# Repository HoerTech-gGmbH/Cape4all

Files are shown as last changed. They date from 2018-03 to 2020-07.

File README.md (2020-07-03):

# Cape4all
Open Hardware Multichannel Sound Interface for Hearing Aid Research on Beaglebone Black

### Hardware Design Files

The published Beaglebone AD/DA Cape schematic and board layout files were developed
by the Institute of Microelectronic Systems at Leibniz Universität Hannover together
with the Videantis GmbH within DFG Cluster of Excellence EXC 1077/1 "Hearing4all".
They are published under the CC BY-NC-SA 4.0 license.

### Kernel Driver Files

These were developed by 64Studio for HörTech gGmbH. They are published under the
GPLv2 license.

See the respective directories for the full license text.

## Publication

Cape4all is described in a contribution to the Linux Audio Conference, see [LAC2018_Cape4all.pdf](LAC2018_Cape4all.pdf). 

If you want to refer to Cape4all in a publication, please cite

Herzke, T., Kayser H., Seifert, C., Maanen, P., Obbard, C., Payá-Vayá, G., Blume, H., 
Hohmann, V., “Open Hardware Multichannel Sound Interface for Hearing Aid Research on 
BeagleBone Black with openMHA: Cape4all,” Linux Audio Conference (LAC2018), May 09, 
Berlin, Germany, 2018.

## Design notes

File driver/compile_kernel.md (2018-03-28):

# Compile  Linux Kernel for Cape4All

Christopher Obbard 13/03/2018
Please mail any questions to     chris <at> 64studio.com

Download & Patch kernel sources:
```
chris@pc:~$ git clone -b linux-4.14.y git://git.kernel.org/pub/scm/linux/kernel/git/stable/linux-stable.git
chris@pc:~/linux-stable$ git apply 0001-add-cape4all-driver-v1.patch
```

Configure Kernel:
```
chris@pc:~/linux-stable$ make distclean
chris@pc:~/linux-stable$ ARCH=arm make omap2plus_defconfig
chris@pc:~/linux-stable$ ARCH=arm make menuconfig
```

Enable the CONFIG_SND_SOC_BONEBLACK_AUDIO_EXTENSION option:
```
 > Device Drivers > Sound card support > Advanced Linux Sound Architecture > ALSA for SoC audio support > <M> SoC Audio support for Boneblack Audio Extension
```

This is also required for the Boneblack board:
```
 > File systems > Native language support > <*> ASCII (United States)
```

Cross-compile Kernel, Modules and Device Tree:
```
 > chris@pc:~/linux-stable$ ARCH=arm CROSS_COMPILE=arm-linux-gnueabihf- make -j6 zImage modules dtbs
```

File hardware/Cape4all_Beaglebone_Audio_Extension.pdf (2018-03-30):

# Beaglebone Audio Extension Technical Reference Manual

## Institute of Microelectronic Systems

## Architectures and Systems Group

## Gottfried Wilhelm Leibniz Universität Hannover

Version | Author | Date | Comment
0.1 | seifert | 25.01.2011 | Document setup and introduction started.
0.2 | seifert | 31.08.2016 | Document update. | Bus collision fix in
schematic and board layout.
0.3 | seifert | 22.09.2016 | Document update. | Detailed jumper and
| | | header descriptions.
0.4 | seifert | 01.12.2017 | Document update. Bus collision fix descrip-
| | | tion in Appendix.
0.5 | seifert | 16.03.2018 | Document update. Corrected Table 3 line 10
| | | and Table 5 line 3.
Institute of Microelectronic Systems | IMS Beaglebone Audio Extension Board Spec.

## Contents

1. Introduction | 5
2. Overview | 6
3. Board Parameters | 7
4. Components | 7
5. Headers | 8
6. Jumpers | 11
List of Figures | 17
List of Tables | 18
Bibliography | 18
Appendices | 19
A. Header | 19
B. Schematics | 20
IMS Beaglebone Audio Extension Board Spec. | Institute of Microelectronic Systems

## 1. Introduction

This technical reference manual describes the functionality of the IMS Beaglebone Audio Extension Board. First an overview of the features is given. After that available headers and connectors are shown and their functionality is described. Later in this manual the jumpers and default configuration settings are listed. At the end the usage with the Beaglebone board is described together with the header pinouts, examples and schematics in the appendix.

## 2. Overview

In this section an overview of the IMS Beaglebone Audio Extension Board is given. The IMS Beaglebone Audio Extension Board is build up using three ADAU1761 low-power codecs from Analog Devices Inc.

Each of the three codecs provides the following features:

- 24-bit stereo audio ADC and DAC: >98 dB SNR
- Sampling rates from 8 kHz to 96 kHz
- Flexible analog input/output mixers
- Stereo digital microphone inputs
- PLL supporting input clocks from 8 MHz to 27 MHz
- Microphone bias reference voltage
- Analog and digital I/O: 1.8 V to 3.65 V
- I2C and SPI control interfaces
- Digital audio serial data I/O: stereo (I2S) and time-division multiplexing (TDM) modes
- 32-lead, 5 mm × 5 mm LFCSP
- -40◦C to +85◦C operating temperature range

For complete informations please refer to the ADAU1761 datasheet [1].

The IMS Beaglebone Audio Extension Board itself is equipped with three 3-pole 3.5mm jacks for stereo microphone input (MIC_IN 1-3) and two 3-pole 3.5mm jacks for stereo headphones output (HP 1-2) shown in figure 1. With the headers P8 and P9 the IMS Beaglebone Audio Extension Board is connected to any compatible Beaglebone board e.g., Beaglebone Black, Beaglebone Green.

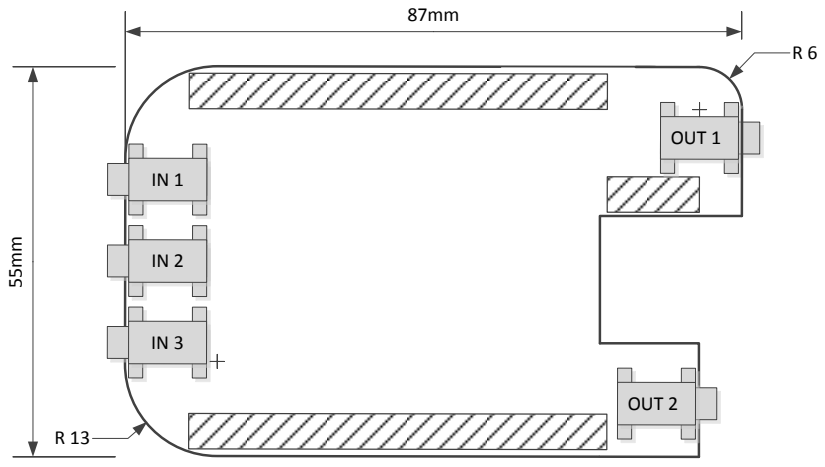
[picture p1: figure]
OUT 2; OUT 1

Figure 1: IMS Beaglebone Audio Extension Board outline

## 3. Board Parameters

- Supply Voltages

– 3.3V from Beaglebone headers P8 and P9

- Internal Voltages from 3.3V supply

– 3.3V for configuration EEPROM

– 3.0V for audio codecs

– 1.0V for hearing aid dummies or microphone bias

## 4. Components

- Power Management

– Voltage Regulation (MAX8902A, MAX8902B)

- Audio (ADAU1761)
- Memory

– Beaglebone configuration EEPROM (CAT24C256)

- Audio bus merger

– 3-input logic OR-Gate (SN74LVC1G332DBVR)

## 5. Headers

The IMS Beaglebone Audio Extension Board headers can be classified as basic headers and extension headers. In the following sections the headers and their functionality will be described.

### 5.1. Basic Headers

For basic connectivity of the IMS Beaglebone Audio Extension Board the headers and connectors listed in table 1 and shown in figure 1 are used.

Name | Type | Description
IN 1 | Audio | 3.5mm stereo microphone input 1
IN 2 | Audio | 3.5mm stereo microphone input 2
IN 3 | Audio | 3.5mm stereo microphone input 3
OUT 1 | Audio | 3.5mm stereo headphone output 1
OUT 2 | Audio | 3.5mm stereo headphone output 2
P8 | Digital | Connector for digital control and audio data transfers to/from Beaglebone.
P9 | Digital | Connector for digital control and audio data transfers to/from Beaglebone.

Table 1: IMS Beaglebone Audio Extension Board basic connectors

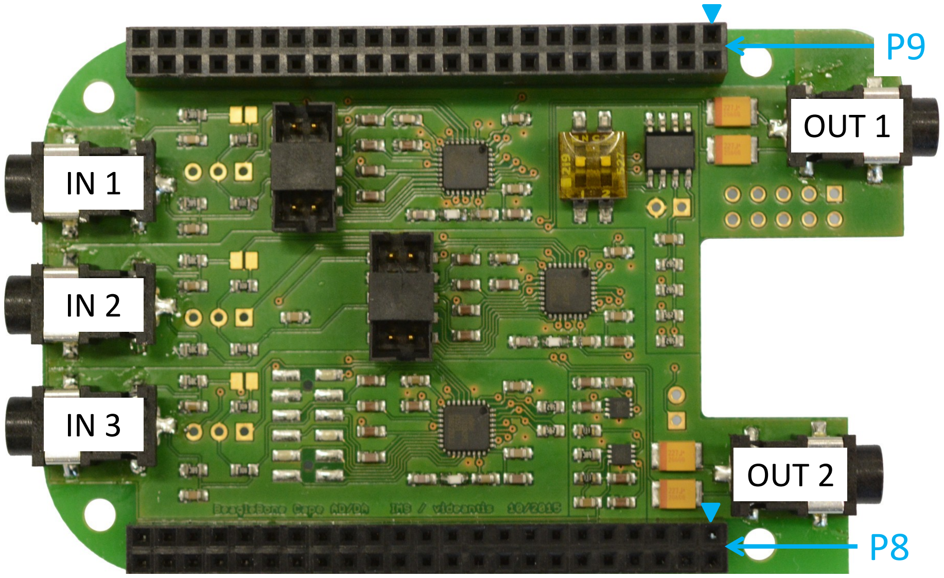
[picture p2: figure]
OUT 1; OUT 2

Figure 2: IMS Beaglebone Audio Extension Board headers

### 5.2. Extension Headers

When more specific connectivity is needed there are some extension headers that provide line level inputs, digital microphone inputs, and line-level outputs. A list of the connectors and headers is given in table 2 and shown in figure 2.

Name | Type | Description
X1 | Mixed | 10-pin audio extension header (2mm pitch)
X2 | Mixed | 10-pin audio extension header (2mm pitch)
X3 | Mixed | 12-pin audio extension header (2mm pitch)

Table 2: IMS Beaglebone Audio Extension Board extension headers

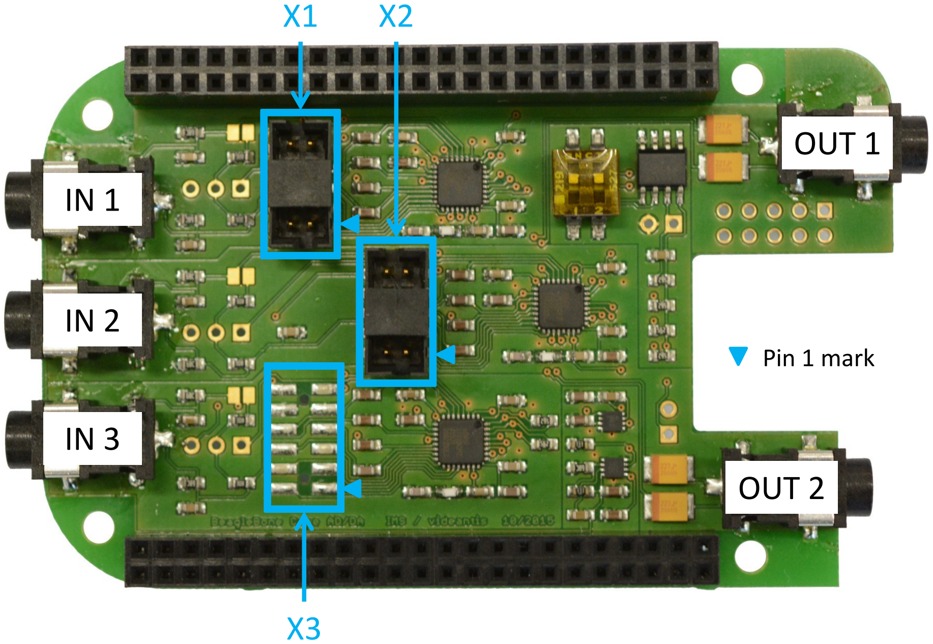
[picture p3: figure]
OUT 1; OUT 2; Pin 1 mark

Figure 3: IMS Beaglebone Audio Extension Board headers

The pinouts of the X1 and X2 headers are symmetrical. Therefore, the pinout of the X1 header is shown in figure 4 and all headers are shown in appendix section A. All the signals with a suffix of 6 belong to the first codec IC1, the suffix 7 belongs to the second codec IC2 and so on. As codec 3 has no dedicated headphone output jack, the pins were added to the X3 header, which can be seen in section A.

Figure 4: IMS Beaglebone Audio Extension Board X1 header pinout

Pin | Name | Description
1 | LOUTN | Left differential line output, negative. Biased
| | at AVDD/2.
2 | LOUTP | Left differential line output, positive. Biased
| | at AVDD/2.
3 | ROUTN | Right Line Output, Negative. | Biased at
| | AVDD/2.
4 | ROUTP | Right Line Output, Positive. | Biased at
| | AVDD/2.
5 | RAUX | Right Channel Single-Ended Auxiliary In-
| | put. Biased at AVDD/2.
6 | LAUX | Left Channel Single-Ended Auxiliary Input.
| | Biased at AVDD/2.
7 & 8 | - | GND connection.
9 | JACKDET | Detect Insertion/Removal of Headphone
| | Plug (JACKDET).
Digital Microphone Stereo Input (MICIN).
10 | +1V | +1V regulated power supply output. En-
| | abled via X5 shown in figure 8

Table 3: IMS Beaglebone Audio Extension Board extension headers

For more information on the pins 1 to 10 of the headers X1-3 please refer to the ADAU1761 datasheet [1].

The digital general-purpose IOs are directly connected to the Beaglebone connectors P8 and P9. The functionality depends on the connected beaglebone board.

## 6. Jumpers

This section describes the configuration jumpers and their default configuration. Also the detailed functionality is given in case of non-default settings.

### 6.1. Microphone input configuration

On the IMS Beaglebone Audio Extension Board there are two jumpers for each microphone input configuration. Another jumper is used for an additional bias voltage supply for all microphone inputs and described in section 6.3. In table 4 the jumpers for each microphone input are listed and after that a schematic and functionality description is given.

Jumper | Microphone-Input | Description
JP11 | IN 1 | Mic. bias enable right channel.
JP12 | IN 1 | Mic. bias enable/selection left channel.
JP21 | IN 2 | Mic. bias enable right channel.
JP22 | IN 2 | Mic. bias enable/selection left channel.
JP31 | IN 3 | Mic. bias enable right channel.
JP32 | IN 3 | Mic. bias enable/selection left channel.

Table 4: IMS Beaglebone Audio Extension Board microphone input jumpers.

For better understanding the schematic of one of the microphone inputs is given in figure 5.

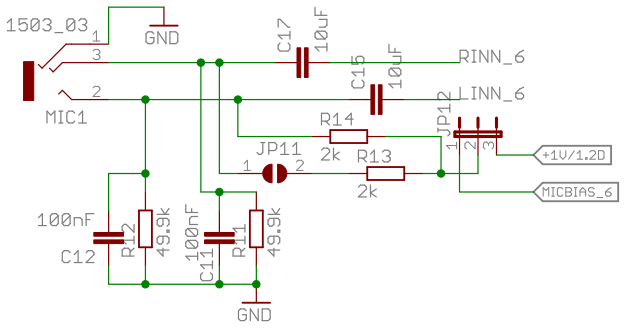
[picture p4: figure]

Figure 5: IMS Beaglebone Audio Extension Board microphone input 1 schematic.

As shown in figure 5 there are mainly two jumpers on each channel for bias voltage configuration. The jumper JPx2 (here x is 1-3) selects the bias voltage source between the bias output of the corresponding codec (in figure 5 codec 6) and a configurable voltage regulator that is set to 1 Volt output in default setting. When selecting one of the bias voltage sources, the supply will be connected to the left input channel (the tip of the 3.5mm input jack) accordingly. If there is also a bias supply needed on the right channel (the ring of the 3.5mm input jack) the jumper JPx1 needs to be shorted. The possible settings of the jumpers are listed in table 5.

| JPx2 | JPx1 | Description
1 | open | open | No bias supply on microphone input.
2 | 1-2 | open | Bias supply of 3.5mm tip with configurable codec
| | | bias output.
3 | 2-3 | open | Bias supply of 3.5mm tip with configurable voltage
| | | regulator output. 1 Volt by default.
4 | 1-2 | shorted | Bias supply of 3.5mm tip and ring with config-
| | | urable codec bias output.
5 | 2-3 | shorted | Bias supply of 3.5mm tip and ring with config-
| | | urable voltage regulator output. 1 Volt by default.

Table 5: IMS Beaglebone Audio Extension Board microphone jumper settings.

Figure 6 shows a detailed view of the microphone input jumpers.

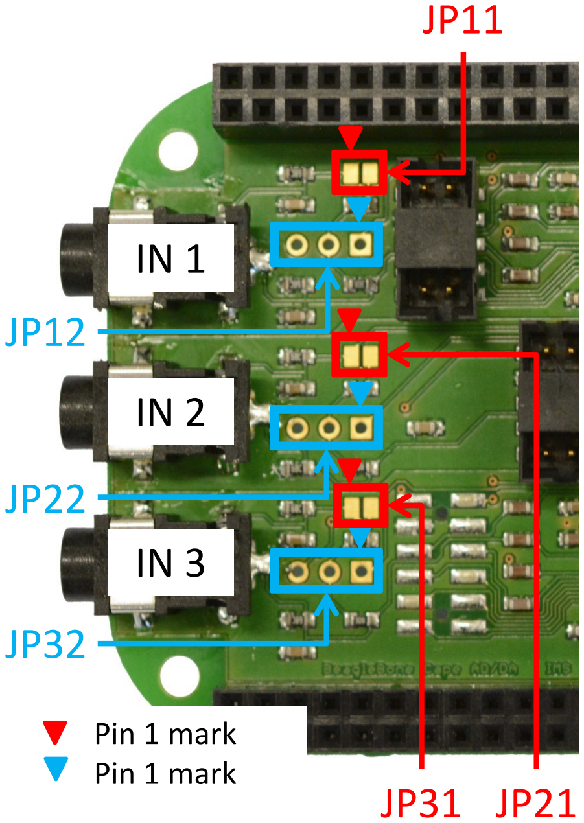
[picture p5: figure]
Pin 1 mark Pin 1 mark

Figure 6: IMS Beaglebone Audio Extension Board microphone input jumpers.

For the voltage regulator settings for bias supply please refer to section 6.3.

### 6.2. Headphone Output

After the microphone input jumpers have been described, this section gives a detailed description of the headphone outputs. The schematic of one headphone output is given in figure 7, while the other headphone output is built up accordingly.

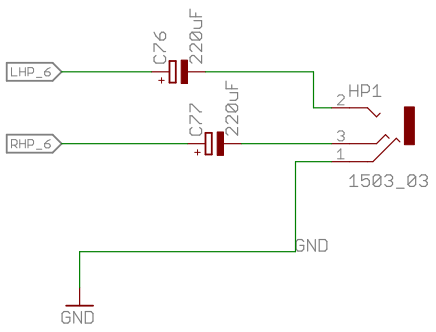
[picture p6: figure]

Figure 7: IMS Beaglebone Audio Extension Board headphone output 1 schematic.

There are DC-blocking capacitors built-in for headphones without built-in capacitors.

### 6.3. Power and EEPROM configuration

This section describes the jumpers for power and EEPROM configuration on the IMS Beaglebone Audio Extension Board. There are two jumpers and one dual switch used for the configuration, which is listed in table 6.

Jumper | Type | Description
X5 | Power | 1V voltage regulator enable if shorted.
X4 | EEPROM | Write protect disabled if shorted.
S4 | EEPROM | Address selection 00, if both switches on.

Table 6: IMS Beaglebone Audio Extension Board power and EEPROM jumpers.

The location of the jumpers is shown in 8.

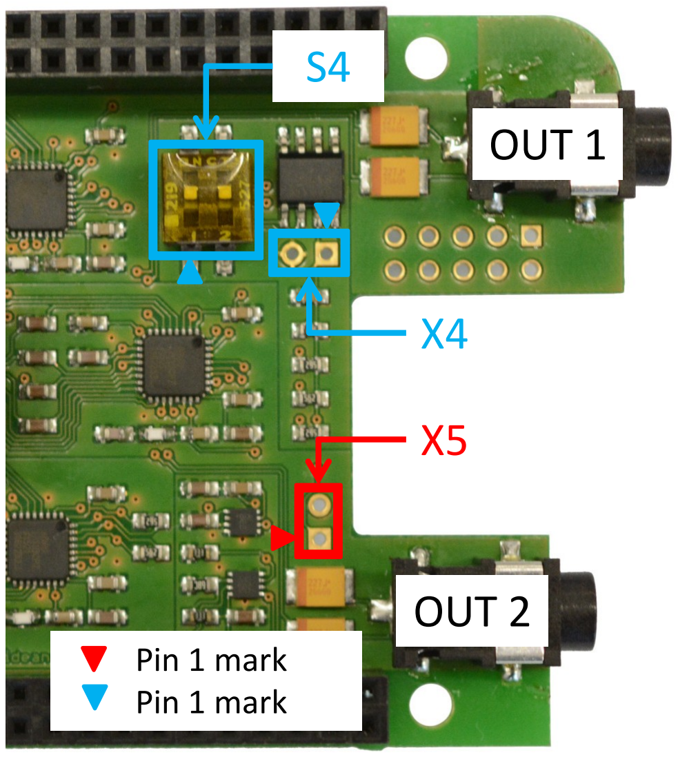
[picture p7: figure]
OUT 1; OUT 2; Pin 1 mark Pin 1 mark

Figure 8: IMS Beaglebone Audio Extension Board power and clock jumpers.

### 6.3.1. Power configuration

The configuration of the microphone bias power supply is done using the X5 jumper. All configurations are listed in table 7.

| X5 | Description
1 | 1-2 | Voltage regulator enabled.
| | Output voltage +1V configured with R51 and R52.
2 | open | Voltage regulator disabled. (Default)

Table 7: IMS Beaglebone Audio Extension Board power jumper settings.

A detailed schematic of the regulator and jumper is given in figure 9.

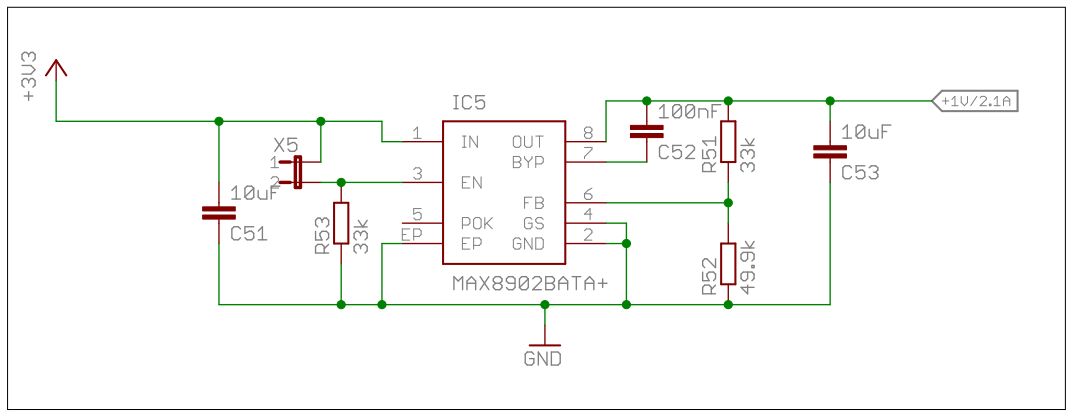
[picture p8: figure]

Figure 9: IMS Beaglebone Audio Extension Board voltage regulator circuit.

### 6.3.2. EEPROM configuration

The configuration of the EEPROM is done with one jumper and a switch. All jumper configurations are listed in table 8.

| X4 | Description
1 | 1-2 | EEPROM write protection disabled (only for ini-
| | tial programming).
2 | open | EEPROM write protection enabled. (Default)

Table 8: IMS Beaglebone Audio Extension Board EEPROM jumper settings.

A detailed schematic of the EEPROM and jumper is given in figure 9.

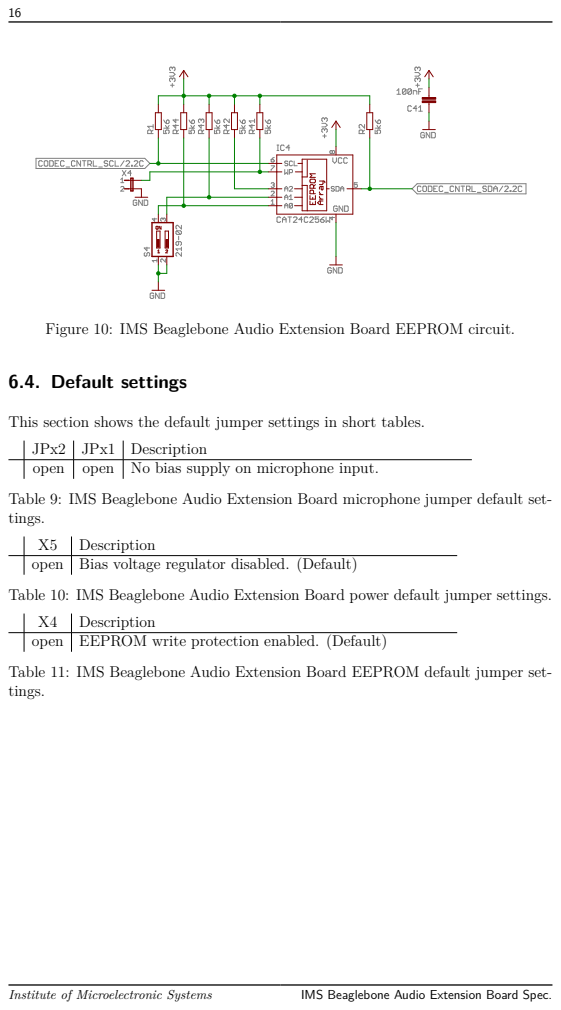
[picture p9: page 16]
6.4. Default settings; JPx2; JPx1; Description; open; No bias supply on microphone input.; Bias voltage regulator disabled. (Default); EEPROM write protection enabled. (Default)

Figure 10: IMS Beaglebone Audio Extension Board EEPROM circuit.

This section shows the default jumper settings in short tables.

Table 9: IMS Beaglebone Audio Extension Board microphone jumper default set-
tings.

Table 10: IMS Beaglebone Audio Extension Board power default jumper settings.

Table 11: IMS Beaglebone Audio Extension Board EEPROM default jumper set-

## List of Figures

5. IMS Beaglebone Audio Extension Board microphone input 1 schematic. 11
6. IMS Beaglebone Audio Extension Board microphone input jumpers. 12
7. IMS Beaglebone Audio Extension Board headphone output 1 schematic. 13
8. IMS Beaglebone Audio Extension Board power and clock jumpers. . 14
9. IMS Beaglebone Audio Extension Board voltage regulator circuit. . 15
14. IMS Beaglebone Audio Extension Board microphone input schematic 20
16. IMS Beaglebone Audio Extension Board headphone output schematic 21
17. IMS Beaglebone Audio Extension Board power supplies schematic . 22
18. IMS Beaglebone Audio Extension Board ADC audio data bus merg-
19. IMS Beaglebone Audio Extension Board schematic P6 & P8 headers 23
20. IMS Beaglebone Audio Extension Board schematic P9 header . . . 23

## List of Tables

4. IMS Beaglebone Audio Extension Board microphone input jumpers. 11
5. IMS Beaglebone Audio Extension Board microphone jumper settings. 12
6. IMS Beaglebone Audio Extension Board power and EEPROM jumpers. 14
7. IMS Beaglebone Audio Extension Board power jumper settings. . . 15
8. IMS Beaglebone Audio Extension Board EEPROM jumper settings. 15
9. IMS Beaglebone Audio Extension Board microphone jumper default
10. IMS Beaglebone Audio Extension Board power default jumper set-
11. IMS Beaglebone Audio Extension Board EEPROM default jumper

## References

[1] Analog Devices Inc. Adau1761 - sigmadsp stereo, low power, 96 khz,24-bit audio codec with integrated pll. http://www.analog.com/static/importedfiles/data_sheets/ADAU1761.pdf, 2009.

## A. Header

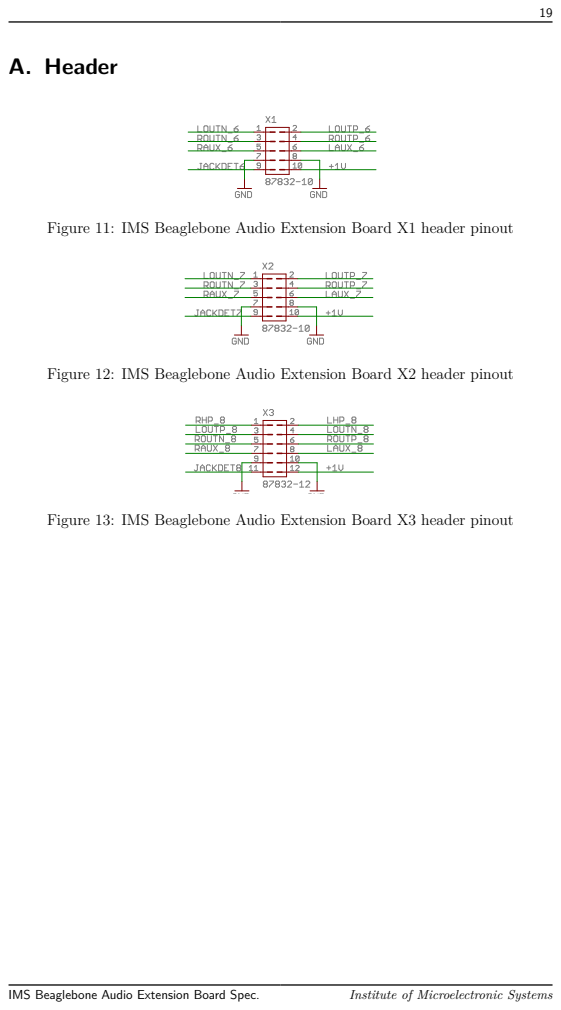
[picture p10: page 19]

Figure 11: IMS Beaglebone Audio Extension Board X1 header pinout

Figure 12: IMS Beaglebone Audio Extension Board X2 header pinout

Figure 13: IMS Beaglebone Audio Extension Board X3 header pinout

## B. Schematics

This section and its subsections show the detailed schematic of the IMS Beaglebone Audio Extension Board.

### B.1. Audio component schematics

The microphone, codec and headphone output schematics are shown for one codec only, as all codecs are connected in the same manner using the indexes 6 to 8. Due to a non tri-state output of the codecs digital audio output pin, the digital audio bus signals of the three codecs CODEC_AUDIO_ADC_SDATA_A, CODEC_AUDIO_ADC_SDATA_B and CODEC_AUDIO_ADC_SDATA_C are merged by the OR gate (IC7) shown in Section B.2.2. This does only provide electrical data corruption. It does not remove data collision due to wrong output timing (like overlap) of the audio codecs. The correct timing slots have to be configured in the codec configuration registers for 4 or 8 channel TDM.

B.1.1. Microphone input

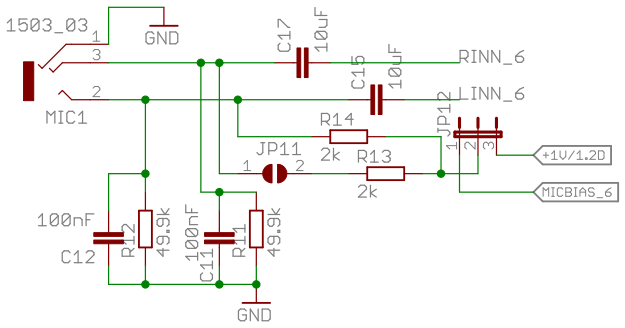
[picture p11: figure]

Figure 14: IMS Beaglebone Audio Extension Board microphone input schematic

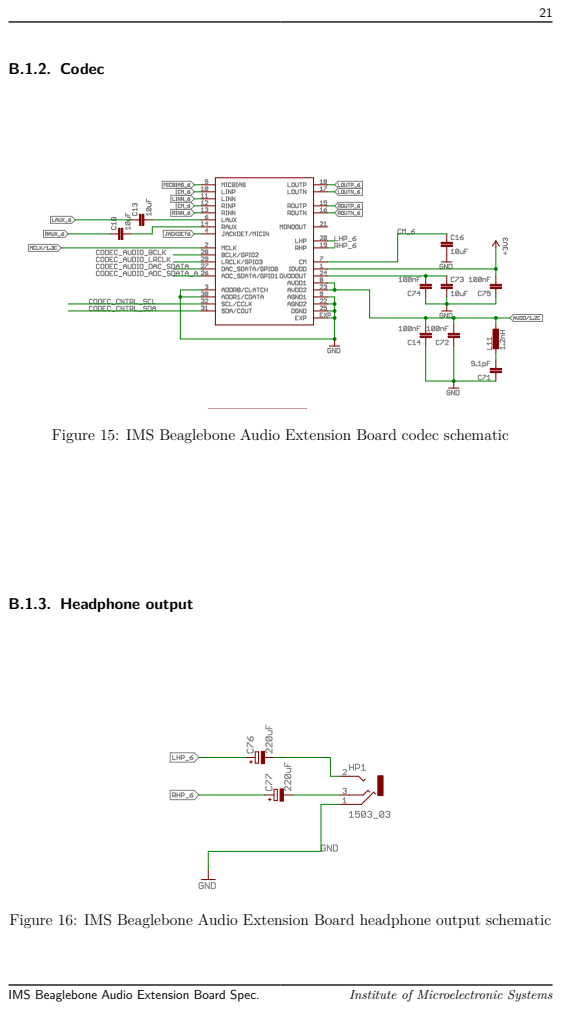
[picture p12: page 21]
B.1.2. Codec; B.1.3. Headphone output

Figure 15: IMS Beaglebone Audio Extension Board codec schematic

Figure 16: IMS Beaglebone Audio Extension Board headphone output schematic

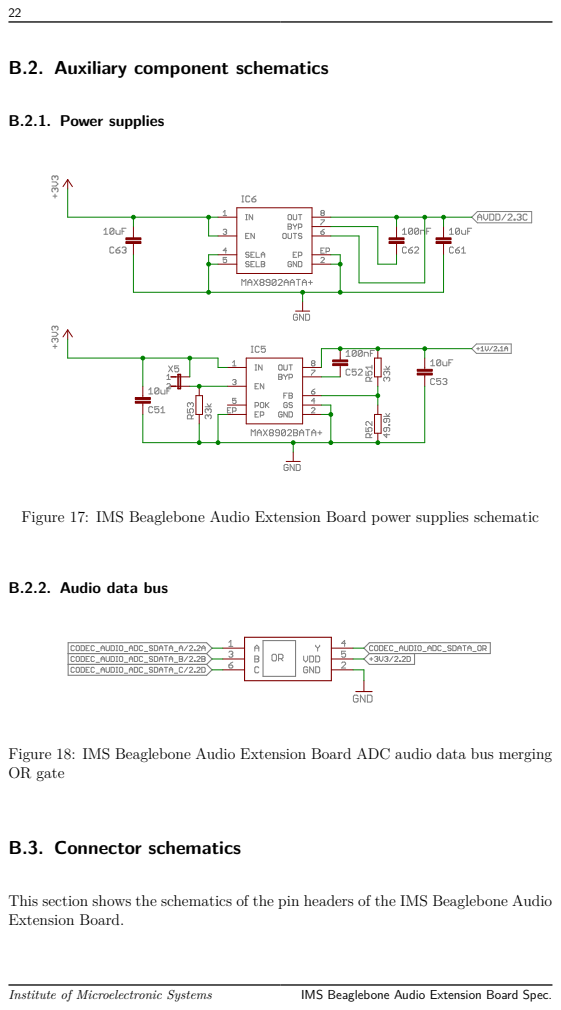
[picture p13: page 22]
B.2.1. Power supplies; B.3. Connector schematics

B.2. Auxiliary component schematics

Figure 17: IMS Beaglebone Audio Extension Board power supplies schematic

B.2.2. Audio data bus

Figure 18: IMS Beaglebone Audio Extension Board ADC audio data bus merging
OR gate

This section shows the schematics of the pin headers of the IMS Beaglebone Audio
Extension Board.

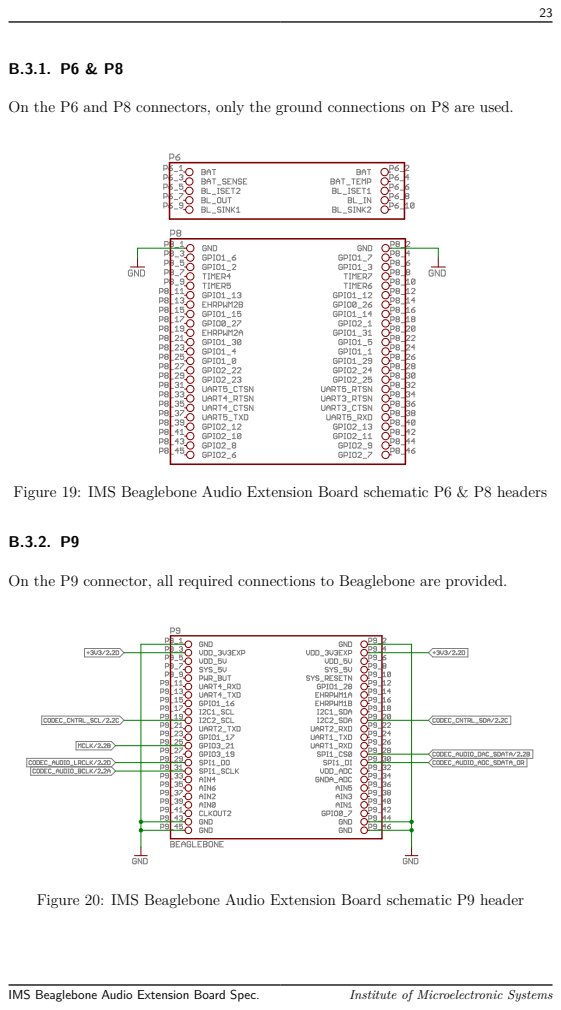
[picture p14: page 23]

On the P6 and P8 connectors, only the ground connections on P8 are used.

Figure 19: IMS Beaglebone Audio Extension Board schematic P6 & P8 headers

On the P9 connector, all required connections to Beaglebone are provided.

Figure 20: IMS Beaglebone Audio Extension Board schematic P9 header

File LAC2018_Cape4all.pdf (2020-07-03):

## Open Hardware Multichannel Sound Interface for Hearing Aid Research on BeagleBone Black with openMHA: Cape4all

Tobias Herzke¹,4 and Hendrik Kayser¹,2,4 and Christopher Seifert³,4 and Paul Maanen¹,4 and Christopher Obbard⁵ and Guillermo Payá-Vayá³,4 and Holger Blume³,4 and Volker Hohmann¹,2,4 1HörTech gGmbH, Marie-Curie-Str. 2, D-26129 Oldenburg, Germany 2Medical Physics, Carl von Ossietzky Universität Oldenburg, D-26111 Oldenburg, Germany

3
Institute of Microelectronic Systems, Leibniz Universität, D-30176 Hannover, Germany 4Cluster of Excellence “Hearing4all” 564 Studio Ltd, Isle of Wight, UK info@openmha.org

Abstract

The paper describes a new multichannel sound interface for the BeagleBone Black, Cape4all. The sound interface has 6 input channels with optional microphone pre-amplifiers and between 4 and 6 output channels. The multichannel sound extension cape for the BeagleBone Black is designed and produced. An ALSA driver is written for it. It is used with the openMHA hearing aid research software to perform hearing aid signal processing on the Beagle-Bone Black with a customized Debian distribution tailored to real-time audio signal processing.

Keywords

Hearing aids, audio signal processing, sound hardware

### 1 Introduction

Hearing aids are the most common form of mitigation for mild and moderate hearing losses. Hearing aids help the wearer to follow conversations and acoustic events in different situations. In the complex acoustic environments that we encounter in our daily life, information about the acoustic scene is inferred at higher stages of the human auditory system and exploited in the brain for, e.g., speech understanding. A hearing loss causes — in addition to reduced sensitivity to soft sounds — a partial loss of this information. Effective signal processing algorithms are required for compensation. For this reason, improving signal processing in hearing aids is an active research topic.
Part of the work in hearing aid research is to develop novel signal processing algorithms that can be used in hearing aids to improve the hearing experience for hard-of-hearing people. Usually, simulations are run and evaluated in terms of objective measures after such an algorithm has been developed mathematically. Results from simulations do not necessarily reflect the benefit of the algorithm a) when integrated in a complete signal processing chain of a hearing aid and b) in a real-world scenario. To assess the usefulness of new hearing aid algorithms for hearing-impaired people, new potential hearing aid signal processing algorithms also have to be tested with hearing impaired test subjects in realistic situations. Running an algorithm under test on an end-user hearing device is practically infeasible as it requires access to a proprietary system of a hearing aid manufacturer, and a large effort for the down-to-hardware implementation is required on such devices. Instead, a software platform can be used to simulate the hearing aid processing chain. The open Master Hearing Aid (openMHA, [HörTech gGmbH and Universität Oldenburg, 2017], [Herzke et al., 2017]) is such a platform. openMHA can be utilized to conduct field tests of hearing aid processing methods running on portable hardware.

The following sections first introduce the software and hardware platforms utilizable to evaluate hearing aid algorithms with hearing-impaired test subjects. We work out the need for a custom multichannel sound interface for a small, portable computer. The subsequent sections report on the hardware design process that resulted in the Cape4all¹ BeagleBone sound interface, the sound driver development, and finally the possible usage of the sound interface for hearing aid research.

1developed in the cluster of excellence “Hearing4all”

### 2 Software and Hardware Platform

for Hearing Aid Research

HörTech and the University of Oldenburg have developed the openMHA [HörTech gGmbH and Universität Oldenburg, 2017], [Herzke et al., 2017] software platform for the development and evaluation of hearing aid algorithms, where individual hearing aid algorithms can be implemented as plugins and loaded at run-time. The platform provides a set of standard algorithms to form a complete hearing aid. It can process audio signal in real-time with a low delay (<10 ms) between sound input and sound output. (The actual delay depends on the sound hardware used for input and output, configuration options like sampling rate and audio buffer size, and also on delay introduced by some signal processing algorithms.)
In its current version 4.5.5, the openMHA software platform can execute on computers with Linux and Mac OS operating system, e.g., in a laboratory environment. Toolboxes for generating virtual sound environments in a laboratory exist (e.g. TASCAR [Grimm et al., 2015]) but the sound environment in a lab — and even more the subject behavior in a lab environment — will always differ from real environments encountered by hearing aid users in real life. To test real-life situations, we have to go outside and into real situations with hearing-impaired users wearing a mobile computer that executes the openMHA and provides the first chance to test new algorithms in real-world situations. In the past, we have used laptops for this purpose but with the advent of small, ARM-based single board computers like the Raspberry Pi, Beagle-Bone, and several others these become an option for executing openMHA that imposes less weight to carry around for the test subjects. The processing power of these devices is significantly lower than that of PCs and laptops, which will always limit the extent and setup of algorithms that can be executed on such a mobile platform (compared to a PC).
openMHA is meant as a common platform to be used by different hearing aid research labs to combine their work. By providing a solid base platform, we want to encourage researchers to implement and publish their algorithms as openMHA plugins so that work can be shared and results can be reproduced by independent labs.
For this purpose, openMHA includes a toolbox library that already contains functions and classes useful to more than one algorithm to speed up implementation of new algorithms. As a key to usability of the software in different usage scenarios openMHA also includes several manuals for different entry levels ranging from plugin developments over application engineering based on available plugins and functionality to the application of the software in the context of audiological research and hearing aid fitting controlled through a graphical user interface (GUI). Step-by-step tutorials on the implementation of openMHA plugins as well as examples of configurations are provided to enable an autonomous familiarization for new users. Some hearing aid algorithms — such as directional microphones — need to process the sound from more than one microphone per ear which is why a multichannel sound card is generally needed to capture the sound from all hearing aid microphones. Professional sound cards can be used for this purpose in stationary laboratory setups. Bus-powered USB sound cards can be used with laptops in mobile evaluation setups, but the choice of bus-powered interfaces with more than 2 input channels is limited. We have observed that the total delay between input and output sounds that can be achieved with USB sound cards is always larger than what can be achieved with similar sound cards with PCI or Expresscard interface. This difference in delay is in the order of 2 ms, which will already affect some hearing aid algorithms. We have also observed that the delay may vary from one start of the sound card to the next with USB sound cards, in the range of 1 ms, which is detrimental to some processing algorithms such as acoustic feedback reduction. (Feedback reduction algorithms are an essential part of a hearing aid processing chain and need the system to be as invariant as possible to work effectively.) The Inter-IC Sound (IIS or I²S) bus — transporting sound data from the SoC²
to the audio codecs
with the AD/DA converters (and back) — is accessible on expansion headers on many of the single-board ARM computers, making it possible to create custom sound interface hardware. Third parties already provide multichannel sound interfaces for popular boards like the BeagleBone Black and the Raspberry Pi. Of these two devices, the BeagleBone Black has the advantage of hardware support for multichannel

2Abbreviation for System on a Chip, the combination of a microprocessor and several peripherals (e.g. graphics unit, sound interface) on a single chip.

audio input/output. See Section 3.1 for details. One multichannel sound interface option for the BeagleBone Black is the BELA cape [Moro et al., 2016]. It provides stereo in/out and additional 8 analogue data acquisition channels. These additional 8 analogue data acquisition channels can also be used to capture audio but do not provide anti-aliasing filters, and achievable sampling rates depend on the number of channels in simultaneous use. The BELA cape makes use of real-time hardware present on the BeagleBone Black. Audio processing algorithms can be compiled to execute on this real-time hardware, process the input channel data, and produce output channel data. Existing Linux audio processing applications using ALSA³ or JACK⁴
[Davis, 2003] and common features of the operating system cannot execute on this real-time hardware.
Another multichannel audio interface developed for BeagleBone platforms is the CTAG face 2|4 [Langer and Manzke, 2015], [Langer, 2015]. Its hardware design is available opensource from GitHub and drivers have been included in official BeagleBoard SD card images. Providing capabilities for multichannel signal processing this device is in principle suitable for hearing aid processing on the BeagleBone Black. A drawback that remains here is the necessity to add external power supply for the microphones connected to the device.
The Octo Audio Injector sound card http: //www.audioinjector.net/rpi-octo-hat offers 6 input channels and 8 output channels for the Raspberry Pi. Although the Raspberry Pi offers no hardware support for more than two sound channels, this sound card manages to offer enough input channels to connect 2 hearing aids with 3 microphones each. A disadvantage of this sound card for hearing aid research is that additional external microphone preamplifiers are needed to raise the microphone signals to line level, which adds to the hardware that test subjects would have to carry around. An example setup for teaching hearing aid signal processing [Schädler, 2017], [Schädler et al., 2018] uses the stereo version of this sound card

3Acronym for Advanced Linux Sound Architecture, name for a system of Linux kernel sound card drivers and user space API to exchange sound data with these drivers.
4 Self-referencing acronym for JACK Audio Connection Kit, a user-space server application and library to connect inputs and outputs of audio applications and sound cards.

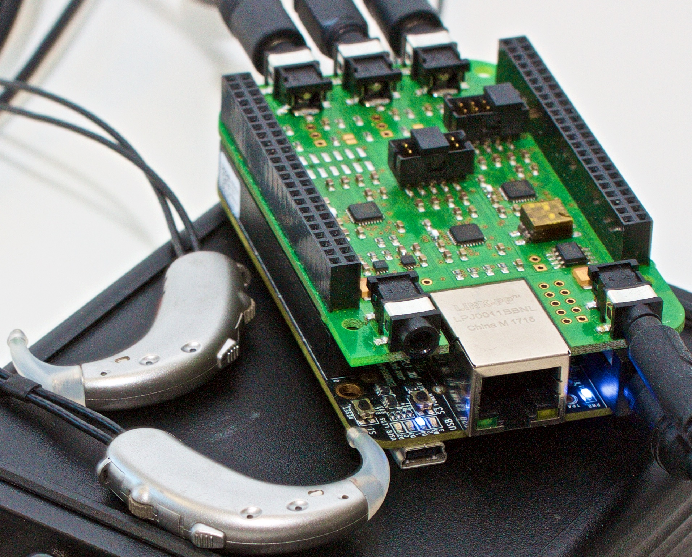
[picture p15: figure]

Figure 1: Cape4all with two hearing aids (each containing three microphones) connected.

together with external microphone preamplifiers.

### 3 Development of the Cape4all

Multichannel Sound Interface for Hearing Aid Research

We have a need for a compact multichannel sound interface for a single-board ARM computer with integrated microphone pre-amplifiers for hearing aid research. Since such a multichannel sound interface was not available, we decided to develop such a sound interface ourselves.

### 3.1 Choice of ARM Board Basis for a

Multichannel Sound Card
In the ongoing developments of the Cluster of Excellence ”Hearing4all”⁵
several audio interfaces were developed proving the inter IC sound (IIS or I²S) in combination with the Analog Devices ADAU1761 [Analog Devices Inc., 2009] stereo audio codec useful [Seifert et al., 2015]. To gain multichannel capabilities, a time division multiplex (TDM) scheme specified for I²S is used. The chosen ADAU1761 codecs support a TDM output scheme. To allow the usage in combination with an ARM-based platform and therefore with openMHA, the BeagleBone Black with native I²S TDM support by the integrated McASP⁶
interfaces was chosen.

### 3.2 Hardware Design

The Cape4all hardware was designed by the Leibniz University Hannover based on [Seifert

5
http://hearing4all.eu/
6Abbreviation for Multichannel Audio Serial Port.

et al., 2015].
In addittion to the I²S TDM output capabilities the Analog Devices ADAU1761 audio codecs have integrated microphone amplifiers. Up to 3 microphones for each ear on a bilateral fitting are assumed in the context of hearing device development. Therefore, 3 stereo audio codecs are integrated on the Cape4all PCB⁷ allowing up to 6 input and output channels simultaneously. Due to the TDM scheme, only five signal connections are required to transport and synchronize all 3 codecs with 6 input and output channels and the McASP interface of the BeagleBone Black.
The board provides standard stereo jacks for connecting off-the-shelf sound hardware as well as pin headers for custom designs. 3 stereo jacks are mounted on the board for the 6 input channels, and 2 additional stereo jacks for the first 4 output channels. The remaining output channels are only accessible through the pin headers. An on-board voltage regulator provides microphone bias voltage which can be switched on and off as needed and routed to different connectors. The bias voltage can be altered by exchanging on-board resistors. For more details, see the reference manual provided with the hardware design files and the driver as download from https://github.com/HoerTech-gGmbH/Cape4all. (https://github.com/HoerTech-gGmbH/Cape4all) Figure 1 shows the hardware in use.

### 3.3 Hardware Tests and Design

Revisions
In the testing process of previously built audio interface boards using the ADAU1761 stereo audio codecs, it was revealed that the internal components of the codecs create bus collision. The I²S TDM bus digital output pins of the codecs do not provide high-resistance state, driving the signal high or low preventing another codec to put data on the same signal. The documentation of the codecs did not give any details helping to avoid the bus collision. In order to avoid this, an OR-gate was added to the board design to merge the signals of the codecs to one signal. This solves the problem on voltage level but does not prevent timing collision due to wrong configuration of the codec outputs. The correct codec configuration is ensured by the ALSA driver (see Section 4). In normal TDM configuration, filling 6 of the available 8 timeslots, all 3 audio codecs are working cor-

7Abbreviation for Printed Circuit Board.

rectly. For further details on I²S TDM signaling see [Seifert et al., 2013].

### 3.4 Release as Open Hardware

The hardware design files are released un-
der | the | Creative | Commons | Attribution-
NonCommercial-ShareAlike | 4.0 | Inter-
national | License | on | GitHub | https:
//github.com/HoerTech-gGmbH/Cape4all.

### 4 Driver development

The ALSA sound driver for the Cape4all sound interface was developed by 64 Studio.
As the Linux kernel already has support for both the McASP Audio Serial Port [Pandey et al., 2009] used on the BeagleBone Black and the ADAU1761 codec [Clausen, 2014] used on the Cape4all, the development by 64 Studio was to create a glue-driver explaining to the SoC the order the codecs are arranged on the Cape4all. The driver registers the cape as effectively one PCM device with three mixer sub-devices (corresponding to the three physical ADAU1761 codecs), each with their own set of controls in the ALSA mixer. Also, the driver sets up the codec’s clock-path, TDM slots and various other default settings.
As the driver exposes the Cape4all as a regular ALSA device with three mixer sub-devices, each with their own ALSA controls, application software may communicate with these devices without any modifications.

### 4.1 Limitations

The McASP used on the BeagleBone Black is clocked from a 24.576 MHz crystal. This limits the available sample rates to be a whole divisor of this clock, for instance 24 kHz or 48 kHz is acceptable but 22.05 kHz or 44.1 kHz is not. The ADAU1761 codecs do not directly support sharing 6 channels between 3 separate codecs on a TDM bus. As a workaround, the TDM mode for transferring 8 channels is used, where 2 channels contain no data. A consequence is that the sound card appears to have 8 channels in ALSA but only the first 6 channels, corresponding to the physical channels, should be used.

### 4.2 Release

The driver code is released as open source software under the GNU General Public License, Version 2 or later, in the same git repository as the hardware design files on GitHub, https: //github.com/HoerTech-gGmbH/Cape4all.

### 5 Usage

As Linux distributions created by SoC development board manufacturers are typically not being suited to audio signal processing and contain a lot of applications that are not useful in this context, a custom Debian distribution has been prepared by 64 Studio. E.g. the JACK Audio Server contained in this custom distribution was built without DBUS support to allow the system to run without a GUI and the final Debian system was tweaked by 64 Studio for basic real-time performance. An image file containing this distribution is available for download together with the hardware design. It contains just the software needed to run openMHA, has device-tree and custom Kernel built-in as well as custom tweaks for increased real-time audio performance.
These steps are needed to prepare a Beagle-Bone Black for multichannel signal processing with openMHA and Cape4all:
- Download and copy image to SD-card
- Download and compile openMHA on the system
- Set up system for higher audio performance according to manual provided
- Start JACK Audio Server with settings according to the openMHA configuration to be run
- Read example configuration provided with openMHA and start processing

The openMHA processes can be accessed at runtime through a TCP/IP connection. This connection can be used to read out and change parameters of the running system. By this means it is possible to run a GUI on a laptop or tablet computer that can be used to control the processing parameters remotely. For details, refer to the openMHA application manual.

### 6 Conclusions

Cape4all is a working, multichannel sound interface for the BeagleBone Black with integrated microphone pre-amplifiers which makes it suitable for hearing aid research, where pre-amplifiers are essential and where a small form factor matters.
A working ALSA driver has been developed that takes care of the proper initialization of the codecs and the multichannel capabilities of the BeagleBone Black and then drives the multichannel sound exchange between user space applications and the codecs on the sound interface.
Both, the hardware design files and the driver, have been published with open licenses on GitHub, https://github.com/HoerTech-gGmbH/Cape4all. (https://github.com/HoerTech-gGmbH/Cape4all)
In its current state, the Cape4all can be run together with a JACK Audio Server on a BeagleBone Black reliably with a 4 ms buffer (128 samples per channel) at a 32 kHz sampling rate. This is the state directly after driver development before any optimization towards shorter audio buffers has been performed. This current state is an important step towards our goal of a mobile hearing aid algorithm evaluation setup, but it needs to be improved to achieve the target overall audio delay below 10 ms between input and output sounds, considering that some of the algorithms will add a small algorithmic delay. Therefore, we are going to further optimize the driver in collaboration with 64 Studio after the initial release to enable smaller audio buffer sizes.

### 7 Acknowledgements

This work was supported by the German Research Foundation (DFG) Cluster of Excellence EXC 1077/1 ”Hearing4all”.
Research reported in this publication was supported by the National Institute On Deafness And Other Communication Disorders of the National Institutes of Health under Award Numbers R01DC015429. The content is solely the responsibility of the authors and does not necessarily represent the official views of the National Institutes of Health.

References

Analog Devices Inc. 2009. ADAU1761 – SigmaDSP stereo, low power, 96 khz, 24-bit audio codec with integrated PLL. http: //www.analog.com/static/importedfiles/data_sheets/ADAU1761.pdf. (http://www.analog.com/static/imported-files/data_sheets/ADAU1761.pdf)

Lars-Peter | Clausen. | 2014. | https:
//git.kernel.org/pub/scm/linux/ kernel/git/torvalds/linux.git/tree/ sound/soc/codecs/adau17x1.c. (https://git.kernel.org/pub/scm/linux/kernel/git/torvalds/linux.git/tree/sound/soc/codecs/adau17x1.c)

Paul Davis. 2003. Jack audio connection kit. http://jackaudio.org/.

Giso Grimm, Joanna Luberadzka, Tobias Herzke, and Volker Hohmann. 2015. Toolbox for acoustic scene creation and rendering (TASCAR) – render methods and research applications. In Proceedings of the Linux Audio Conference, pages 1–7, Mainz. Johannes Gutenberg-Universität.

Tobias Herzke, Hendrik Kayser, Frasher Loshaj, Giso Grimm, and Volker Hohmann. 2017. Open signal processing software platform for hearing aid research (openMHA). In Proceedings of the Linux Audio Conference, pages 35–42, Saint-Etienne. Université Jean ´ Monnet.

HörTech gGmbH and Universität Oldenburg. 2017. openMHA web site on GitHub. http: //www.openmha.org/.

Henrik Langer and Robert Manzke. 2015.
Linux-based | low-latency | multichannel
audio system (CTAG face2—4). | http:
//www.creative-technologies.de/linux-based-low-latency-multichannelaudio-system-2/. (http://www.creative-technologies.de/linux-based-low-latency-multichannel-audio-system-2/)
Henrik | Langer. | 2015. | Linuxbasiertes
Mehrkanal-Audiosystem | mit | niedriger
Latenz.

Giulio Moro, Astrid Bin, Robert H Jack, Christian Heinrichs, Andrew P McPherson, et al. 2016. Making high-performance embedded instruments with bela and pure data.

Nirmal | Pandey, | Suresh | Rajashekara,
and | Steve | Chen. | 2009. | https:
//git.kernel.org/pub/scm/linux/ kernel/git/torvalds/linux.git/tree/ sound/soc/davinci/davinci-mcasp.c. (https://git.kernel.org/pub/scm/linux/kernel/git/torvalds/linux.git/tree/sound/soc/davinci/davinci-mcasp.c)

Marc René Schädler, Hendrik Kayser, and Tobias Herzke. 2018. Pi hearing aid. The MagPi (Raspberry Pi Magazine), 67:34–35.

Marc René Schädler. 2017. openMHA on Raspberry Pi. https://github.com/m-r-s/hearingaid-prototype. (https://github.com/m-r-s/hearingaid-prototype)

Christopher Seifert, Guillermo Payá-Vayá, and Holger Blume. 2013. A multi-channel audio extension board for binaural hearing aid systems. In Proceedings of ICT. OPEN. Conference ICT. OPEN, pages 33–37.

Christopher Seifert, Guillermo Payá-Vayá, Holger Blume, Tobias Herzke, and Volker Hohmann. 2015. A mobile SoC-based platform for evaluating hearing aid algorithms and architectures. In Consumer Electronics-Berlin (ICCE-Berlin), 2015 IEEE 5th International Conference on, pages 93–97. IEEE.

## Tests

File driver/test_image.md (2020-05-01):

You can use openMHA mahalia images which contain the driver and autostart
Jack on the sound card from http://mahalia.openmha.org/ for testing.

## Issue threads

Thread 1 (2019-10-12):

Cape4All test image location?

bitswype, 2019-10-12:
Where is the Cape4All test image located?  The markdown page seems to have a placeholder for the URL.

tobiasherzke, 2019-10-16:
You are referring to file driver/test_image.md. Thanks for the report. We need to fix this file.

You can use openMHA mahalia images which contain the driver and autostart Jack on the sound card from http://mahalia.openmha.org/ for testing.

Closed 2020-05-02.

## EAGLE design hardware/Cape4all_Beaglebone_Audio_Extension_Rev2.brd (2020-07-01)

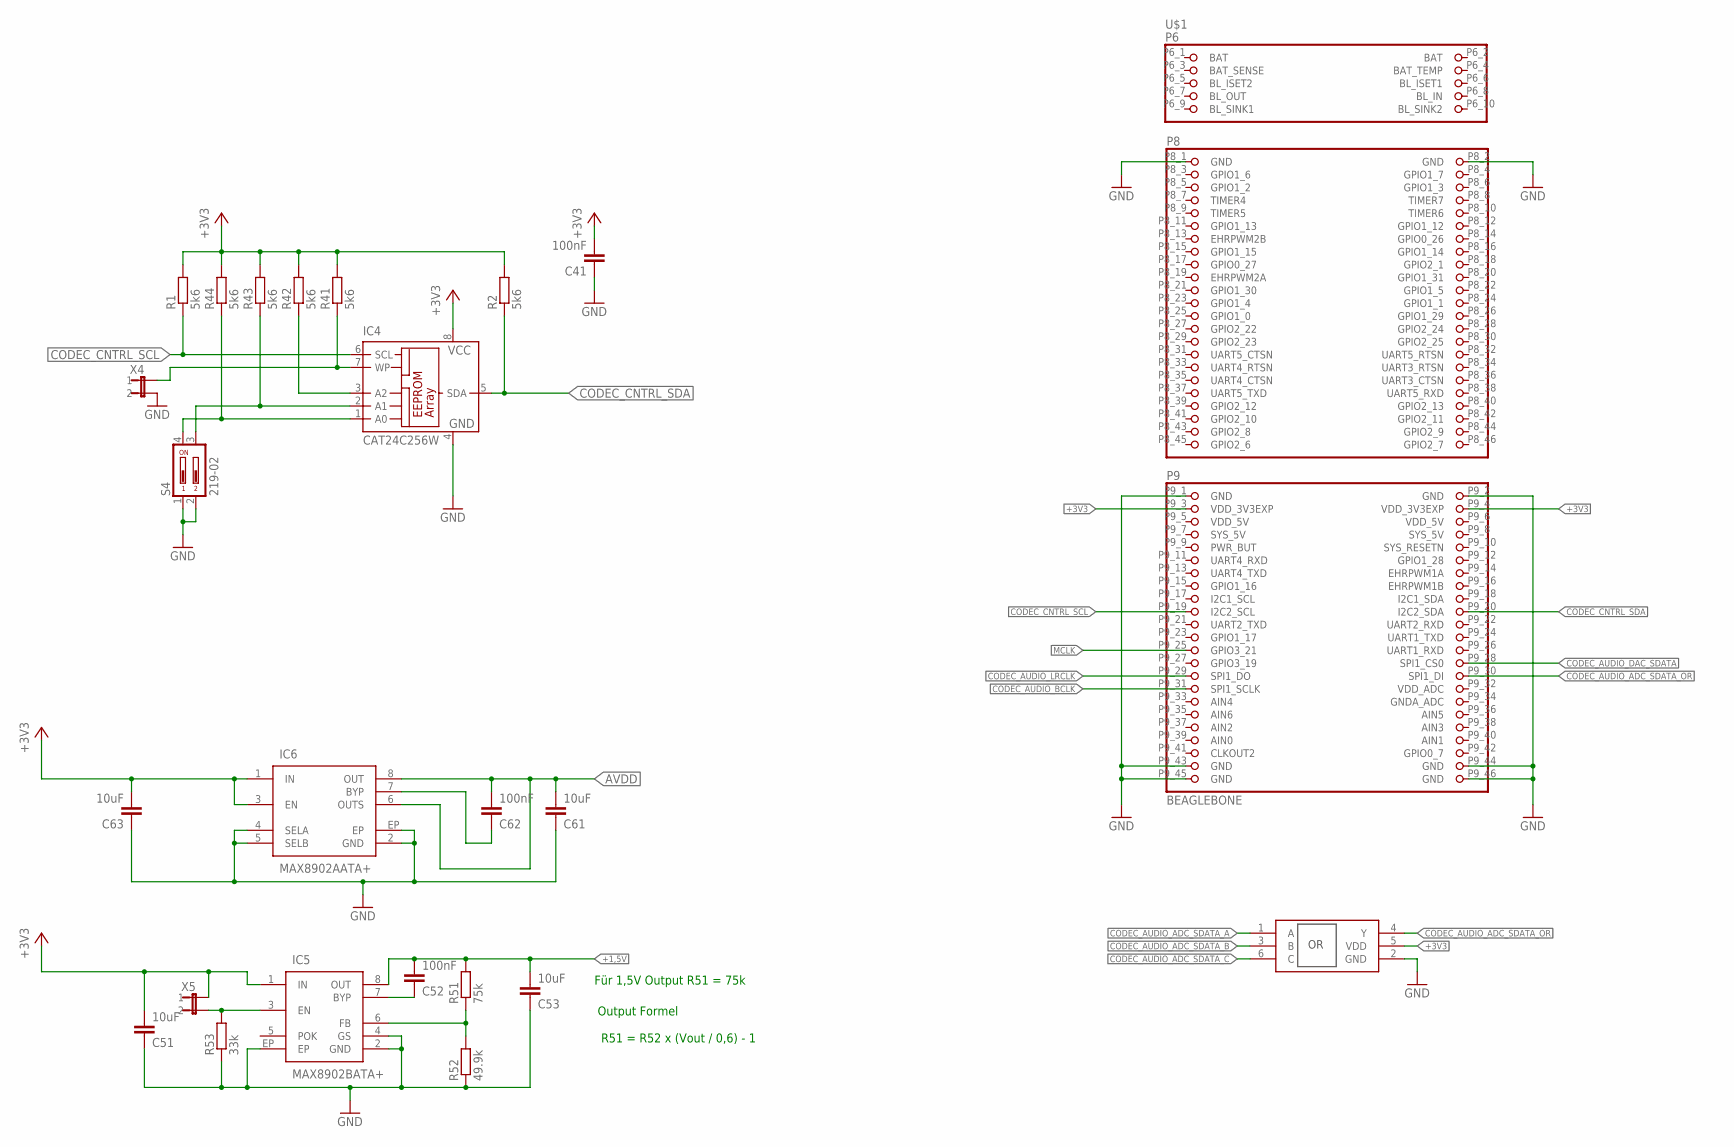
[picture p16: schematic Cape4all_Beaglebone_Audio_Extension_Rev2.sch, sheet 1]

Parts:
C41, C52, C62: 100nF; C0603
C51, C53, C61, C63: 10uF; C0603
IC4: CAT24C256W; SO-08
IC5: MAX8902BATA+; 8-TDFN-EP
IC6: MAX8902AATA+; 8-TDFN-EP
IC7: SN74LVC1G332SMD; SOT23-6L
R1, R2, R41, R42, R43, R44: 5k6; R0603
R51: 75k; R0603
R52: 49.9k; R0603
R53: 33k; R0603
S4: 219-02; CTS-219-02
U$1: BEAGLEBONE
X4, X5: JP1X2

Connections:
+1,5V: C52.2, C53.2, IC5.8 (OUT), R51.2; also elsewhere on the board
+3V3: C41.2, C51.2, C63.2, IC4.8 (VCC), IC5.1 (IN), IC6.1 (IN), IC6.3 (EN), IC7.5 (VDD), R1.2, R2.2, R41.2, R42.2, R43.2, R44.2, U$1.P9_3 (VDD_3V3EXP), U$1.P9_4 (VDD_3V3EXP), X5.1; also elsewhere on the board
AVDD: C61.2, C62.2, IC6.6 (OUTS), IC6.8 (OUT); also elsewhere on the board
CODEC_AUDIO_ADC_SDATA_A: IC7.1 (A); also elsewhere on the board
CODEC_AUDIO_ADC_SDATA_B: IC7.3 (B); also elsewhere on the board
CODEC_AUDIO_ADC_SDATA_C: IC7.6 (C); also elsewhere on the board
CODEC_AUDIO_ADC_SDATA_OR: IC7.4 (Y), U$1.P9_30 (SPI1_DI)
CODEC_AUDIO_BCLK: U$1.P9_31 (SPI1_SCLK); also elsewhere on the board
CODEC_AUDIO_DAC_SDATA: U$1.P9_28 (SPI1_CS0); also elsewhere on the board
CODEC_AUDIO_LRCLK: U$1.P9_29 (SPI1_DO); also elsewhere on the board
CODEC_CNTRL_SCL: IC4.6 (SCL), R1.1, U$1.P9_19 (I2C2_SCL); also elsewhere on the board
CODEC_CNTRL_SDA: IC4.5 (SDA), R2.1, U$1.P9_20 (I2C2_SDA); also elsewhere on the board
GND: C41.1, C51.1, C53.1, C61.1, C63.1, IC4.4 (GND), IC5.2 (GND), IC5.4 (GS), IC5.EP, IC6.2 (GND), IC6.4 (SELA), IC6.5 (SELB), IC6.EP, IC7.2 (GND), R52.1, R53.1, S4.1, S4.2, U$1.P8_1 (GND), U$1.P8_2 (GND), U$1.P9_1 (GND), U$1.P9_2 (GND), U$1.P9_43 (GND), U$1.P9_44 (GND), U$1.P9_45 (GND), U$1.P9_46 (GND), X4.2; also elsewhere on the board
MCLK: U$1.P9_25 (GPIO3_21); also elsewhere on the board
unnamed: IC5.3 (EN), R53.2, X5.2
unnamed: IC4.3 (A2), R42.1
unnamed: IC4.2 (A1), R43.1, S4.3
unnamed: IC4.1 (A0), R44.1, S4.4
unnamed: IC4.7 (WP), R41.1, X4.1
unnamed: C52.1, IC5.7 (BYP)
unnamed: IC5.6 (FB), R51.1, R52.2
unnamed: C62.1, IC6.7 (BYP)

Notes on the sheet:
Für 1,5V Output R51 = 75k
Output Formel R51 = R52 x (Vout / 0,6) - 1

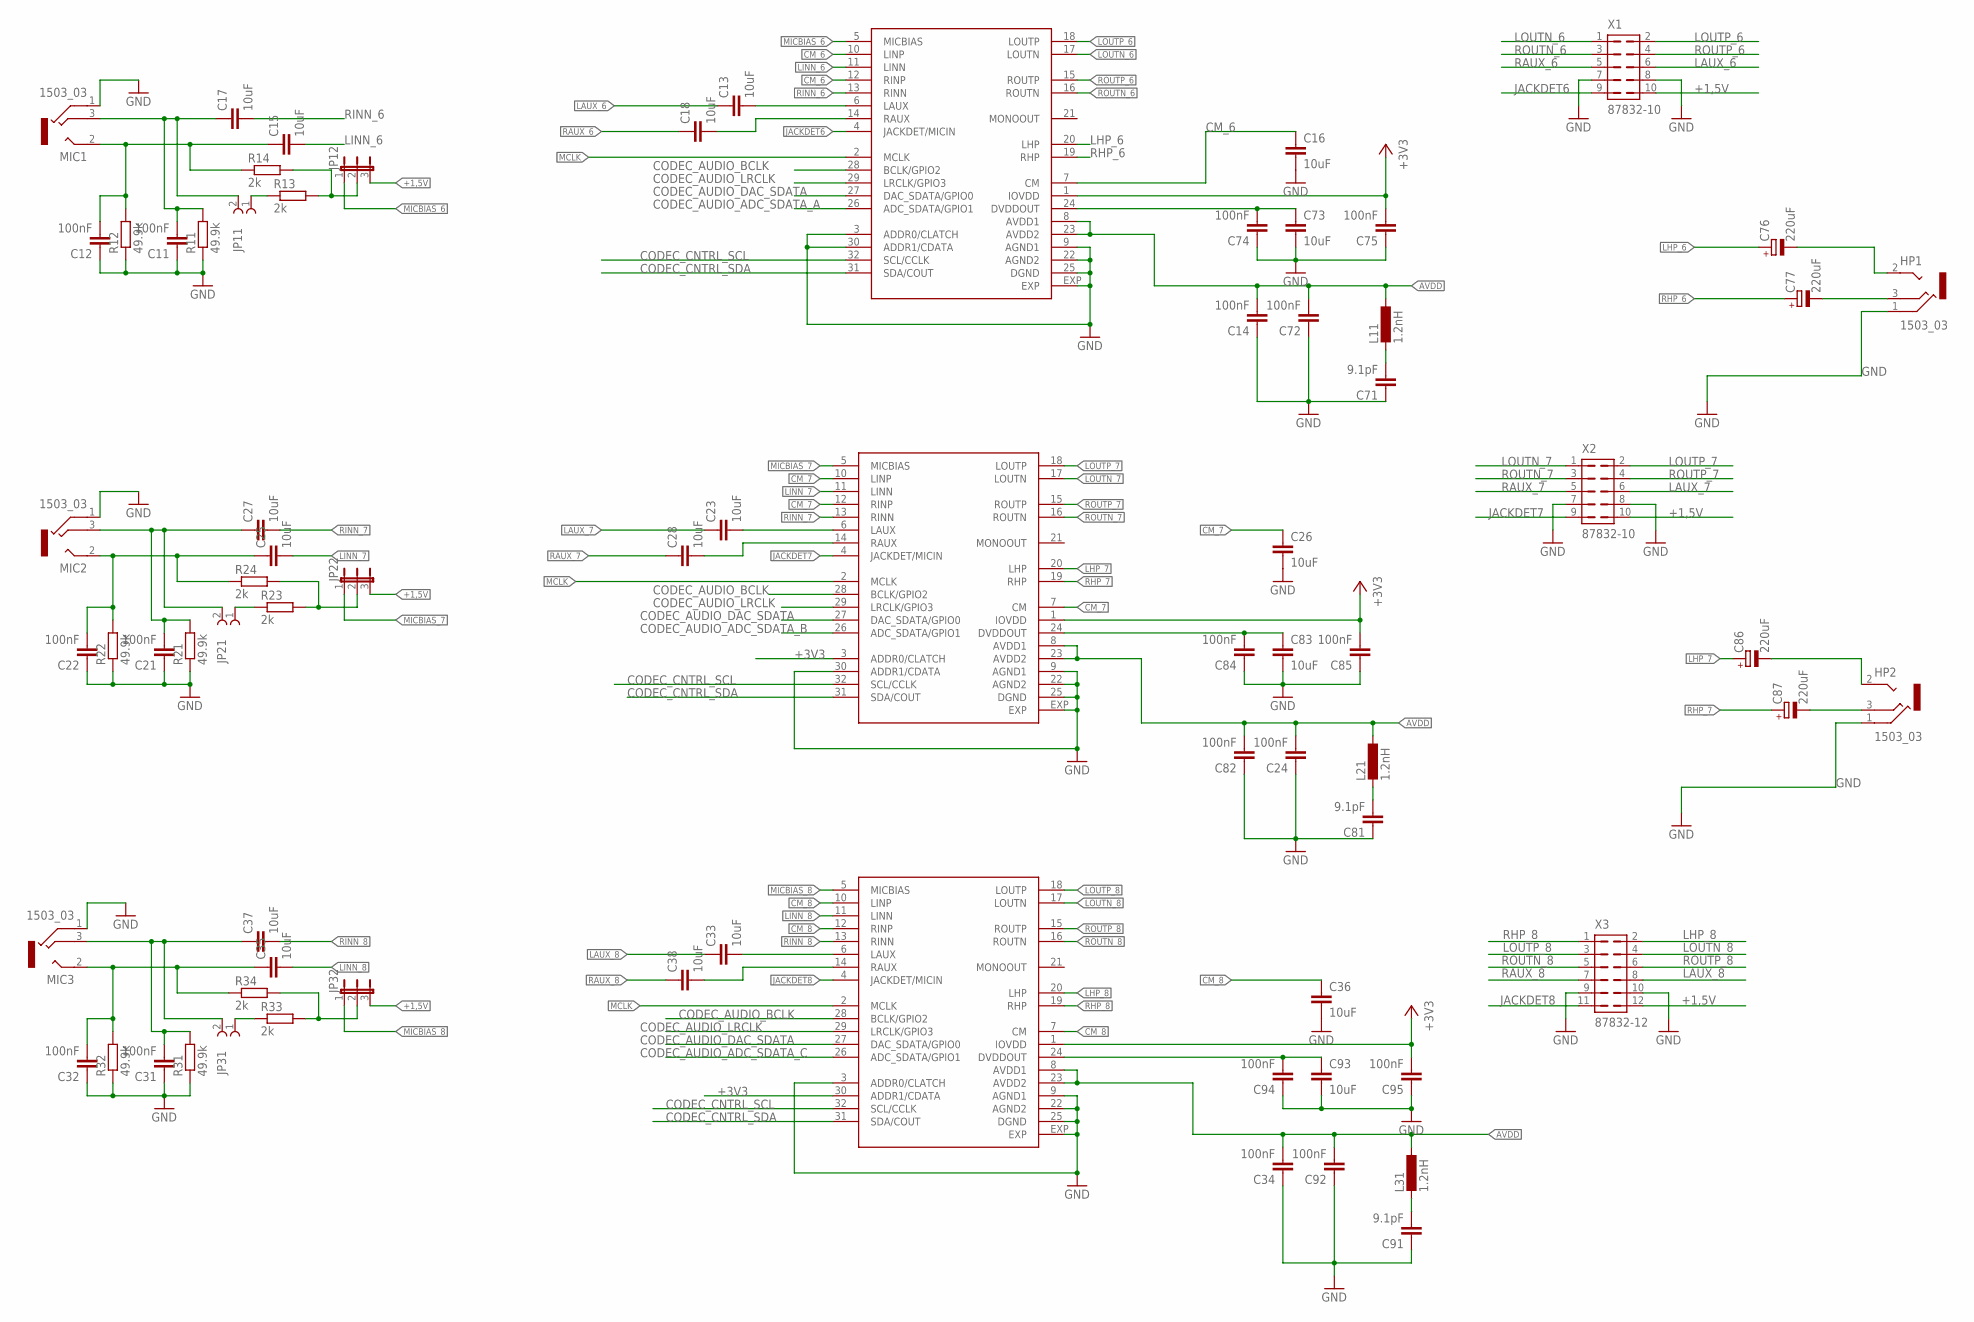
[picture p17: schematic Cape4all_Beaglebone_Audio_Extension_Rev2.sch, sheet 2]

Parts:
C11, C12, C14, C21, C22, C24, C31, C32, C34, C72, C74, C75, C82, C84, C85, C92, C94, C95: 100nF; C0603
C13, C15, C16, C17, C18, C23, C25, C26, C27, C28, C33, C35, C36, C37, C38, C73, C83, C93: 10uF; C0603
C71, C81, C91: 9.1pF; C0603
C76, C77, C86, C87: 220uF; B/3528-21R
HP1, HP2: 1503_03
IC1, IC2, IC3: ADAU1761BCPZ; LFCSP32
JP11, JP21, JP31: 62000211121
JP12, JP22, JP32: JP1X3
L11, L21, L31: 1.2nH; R0603
MIC1, MIC2, MIC3: 1503_03
R11, R12, R21, R22, R31, R32: 49.9k; R0603
R13, R14, R23, R24, R33, R34: 2k; R0603
X1, X2: 87832-10
X3: 87832-12

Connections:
+1,5V: JP12.3, JP22.3, JP32.3, X1.10, X2.10, X3.12; also elsewhere on the board
+3V3: C75.2, C85.2, C95.2, IC1.1 (IOVDD), IC2.1 (IOVDD), IC2.3 (ADDR0/CLATCH), IC3.1 (IOVDD), IC3.30 (ADDR1/CDATA); also elsewhere on the board
AVDD: C14.2, C24.2, C34.2, C72.2, C82.2, C92.2, IC1.8 (AVDD1), IC1.23 (AVDD2), IC2.8 (AVDD1), IC2.23 (AVDD2), IC3.8 (AVDD1), IC3.23 (AVDD2), L11.1, L21.1, L31.1; also elsewhere on the board
CM_6: C16.1, IC1.7 (CM), IC1.10 (LINP), IC1.12 (RINP)
CM_7: C26.1, IC2.7 (CM), IC2.10 (LINP), IC2.12 (RINP)
CM_8: C36.1, IC3.7 (CM), IC3.10 (LINP), IC3.12 (RINP)
CODEC_AUDIO_ADC_SDATA_A: IC1.26 (ADC_SDATA/GPIO1); also elsewhere on the board
CODEC_AUDIO_ADC_SDATA_B: IC2.26 (ADC_SDATA/GPIO1); also elsewhere on the board
CODEC_AUDIO_ADC_SDATA_C: IC3.26 (ADC_SDATA/GPIO1); also elsewhere on the board
CODEC_AUDIO_BCLK: IC1.28 (BCLK/GPIO2), IC2.28 (BCLK/GPIO2), IC3.28 (BCLK/GPIO2); also elsewhere on the board
CODEC_AUDIO_DAC_SDATA: IC1.27 (DAC_SDATA/GPIO0), IC2.27 (DAC_SDATA/GPIO0), IC3.27 (DAC_SDATA/GPIO0); also elsewhere on the board
CODEC_AUDIO_LRCLK: IC1.29 (LRCLK/GPIO3), IC2.29 (LRCLK/GPIO3), IC3.29 (LRCLK/GPIO3); also elsewhere on the board
CODEC_CNTRL_SCL: IC1.32 (SCL/CCLK), IC2.32 (SCL/CCLK), IC3.32 (SCL/CCLK); also elsewhere on the board
CODEC_CNTRL_SDA: IC1.31 (SDA/COUT), IC2.31 (SDA/COUT), IC3.31 (SDA/COUT); also elsewhere on the board
DVDDOUT_6: C73.1, C74.2, IC1.24 (DVDDOUT)
DVDDOUT_7: C83.1, C84.2, IC2.24 (DVDDOUT)
DVDDOUT_8: C93.1, C94.2, IC3.24 (DVDDOUT)
GND: C11.1, C12.1, C14.1, C16.2, C21.1, C22.1, C24.1, C26.2, C31.1, C32.1, C34.1, C36.2, C71.1, C72.1, C73.2, C74.1, C75.1, C81.1, C82.1, C83.2, C84.1, C85.1, C91.1, C92.1, C93.2, C94.1, C95.1, HP1.1, HP2.1, IC1.3 (ADDR0/CLATCH), IC1.9 (AGND1), IC1.22 (AGND2), IC1.25 (DGND), IC1.30 (ADDR1/CDATA), IC1.EXP, IC2.9 (AGND1), IC2.22 (AGND2), IC2.25 (DGND), IC2.30 (ADDR1/CDATA), IC2.EXP, IC3.3 (ADDR0/CLATCH), IC3.9 (AGND1), IC3.22 (AGND2), IC3.25 (DGND), IC3.EXP, MIC1.1, MIC2.1, MIC3.1, R11.1, R12.1, R21.1, R22.1, R31.1, R32.1, X1.7, X1.8, X2.7, X2.8, X3.9, X3.10; also elsewhere on the board
JACKDET6: IC1.4 (JACKDET/MICIN), X1.9
JACKDET7: IC2.4 (JACKDET/MICIN), X2.9
JACKDET8: IC3.4 (JACKDET/MICIN), X3.11
LAUX_6: C13.1, X1.6
LAUX_7: C23.1, X2.6
LAUX_8: C33.1, X3.8
LHP_6: C76.+, IC1.20 (LHP)
LHP_7: C86.+, IC2.20 (LHP)
LHP_8: IC3.20 (LHP), X3.2
LINN_6: C15.2, IC1.11 (LINN)
LINN_7: C25.2, IC2.11 (LINN)
LINN_8: C35.2, IC3.11 (LINN)
LOUTN_6: IC1.17 (LOUTN), X1.1
LOUTN_7: IC2.17 (LOUTN), X2.1
LOUTN_8: IC3.17 (LOUTN), X3.4
LOUTP_6: IC1.18 (LOUTP), X1.2
LOUTP_7: IC2.18 (LOUTP), X2.2
LOUTP_8: IC3.18 (LOUTP), X3.3
MCLK: IC1.2 (MCLK), IC2.2 (MCLK), IC3.2 (MCLK); also elsewhere on the board
MIC1L: C12.2, C15.1, MIC1.2, R12.2, R14.1
MIC1R: C11.2, C17.1, JP11.2 (1), MIC1.3, R11.2
MIC2L: C22.2, C25.1, MIC2.2, R22.2, R24.1
MIC2R: C21.2, C27.1, JP21.2 (1), MIC2.3, R21.2
MIC3L: C32.2, C35.1, MIC3.2, R32.2, R34.1
MIC3R: C31.2, C37.1, JP31.2 (1), MIC3.3, R31.2
MICBIAS_6: IC1.5 (MICBIAS), JP12.1
MICBIAS_7: IC2.5 (MICBIAS), JP22.1
MICBIAS_8: IC3.5 (MICBIAS), JP32.1
unnamed: C91.2, L31.2
unnamed: C71.2, L11.2
unnamed: C23.2, IC2.6 (LAUX)
unnamed: C28.2, IC2.14 (RAUX)
unnamed: C13.2, IC1.6 (LAUX)
unnamed: C18.2, IC1.14 (RAUX)
unnamed: C33.2, IC3.6 (LAUX)
unnamed: C38.2, IC3.14 (RAUX)
unnamed: JP11.1 (2), R13.1
unnamed: JP21.1 (2), R23.1
unnamed: JP31.1 (2), R33.1
unnamed: JP32.2, R33.2, R34.2
unnamed: JP12.2, R13.2, R14.2
unnamed: JP22.2, R23.2, R24.2
unnamed: C87.-, HP2.3
unnamed: C86.-, HP2.2
unnamed: C81.2, L21.2
unnamed: C77.-, HP1.3
unnamed: C76.-, HP1.2
RAUX_6: C18.1, X1.5
RAUX_7: C28.1, X2.5
RAUX_8: C38.1, X3.7
RHP_6: C77.+, IC1.19 (RHP)
RHP_7: C87.+, IC2.19 (RHP)
RHP_8: IC3.19 (RHP), X3.1
RINN_6: C17.2, IC1.13 (RINN)
RINN_7: C27.2, IC2.13 (RINN)
RINN_8: C37.2, IC3.13 (RINN)
ROUTN_6: IC1.16 (ROUTN), X1.3
ROUTN_7: IC2.16 (ROUTN), X2.3
ROUTN_8: IC3.16 (ROUTN), X3.5
ROUTP_6: IC1.15 (ROUTP), X1.4
ROUTP_7: IC2.15 (ROUTP), X2.4
ROUTP_8: IC3.15 (ROUTP), X3.6

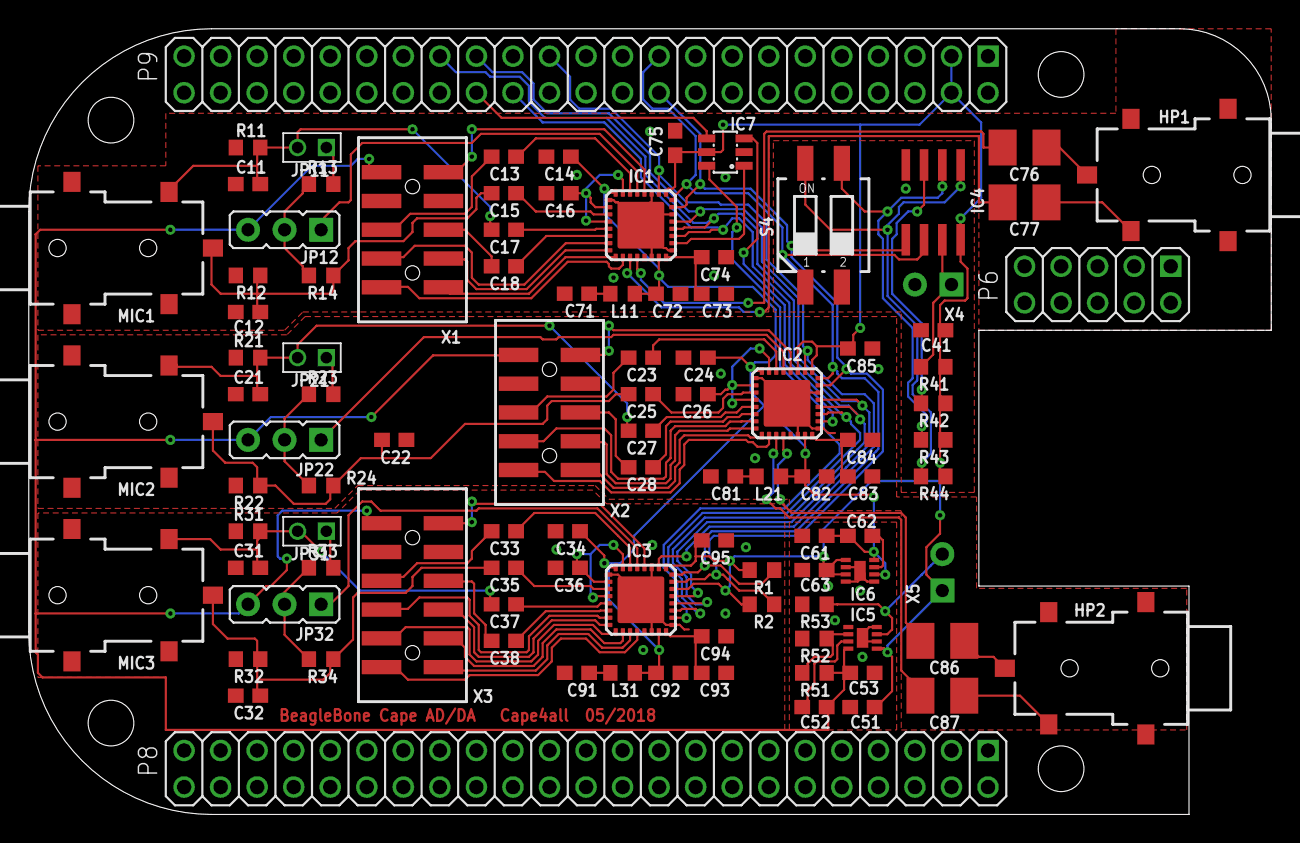
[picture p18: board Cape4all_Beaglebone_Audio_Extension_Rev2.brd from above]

Board: 4 copper layers, 86.4 x 54.6 mm, 99 parts (0 on the bottom side), 89 nets.

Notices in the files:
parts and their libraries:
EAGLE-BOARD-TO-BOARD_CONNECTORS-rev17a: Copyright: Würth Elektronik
